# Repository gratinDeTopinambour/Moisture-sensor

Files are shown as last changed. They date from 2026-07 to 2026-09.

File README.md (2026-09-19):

# 🌿 Capacitive Soil Moisture Sensor

A complete **open-source capacitive soil moisture sensor project** based on the **STM32U073CB** microcontroller.

This repository contains all resources for the project:
* 📐 **3D Design**: Modular enclosure for 3D printing.
* 🔌 **Electronics (V1 & V2)**: KiCad files, Gerbers, BOM, PDF schematics, and 3D models.
* 💻 **Firmware**: C/C++ source code optimized for STM32 (STM32CubeIDE / STM32CubeMX project).
* 📖 **Documentation**: User manual and component datasheets.

---

## 🖼️ Project Overview

| Complete Enclosure | Assembled PCB |
| :---: | :---: |
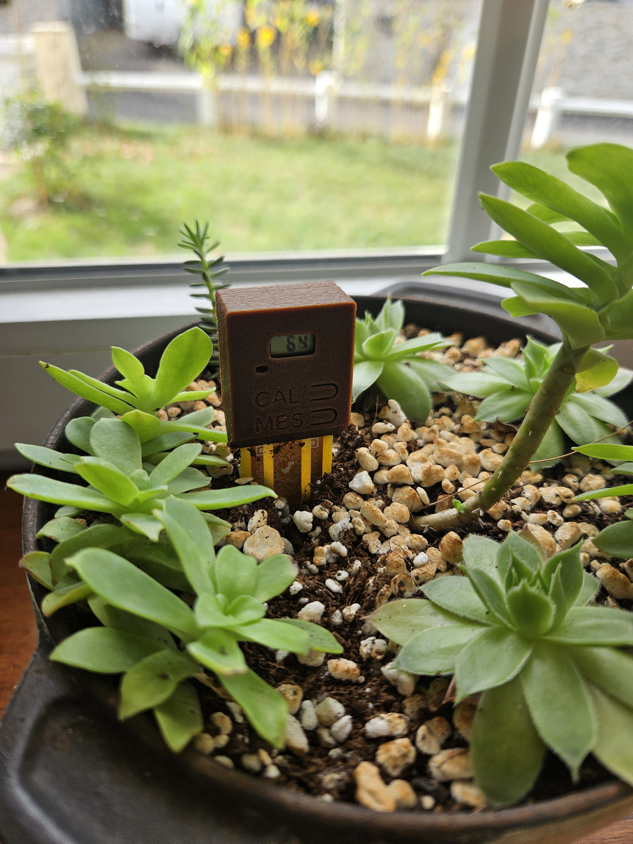
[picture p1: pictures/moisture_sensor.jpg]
Moisture Sensor
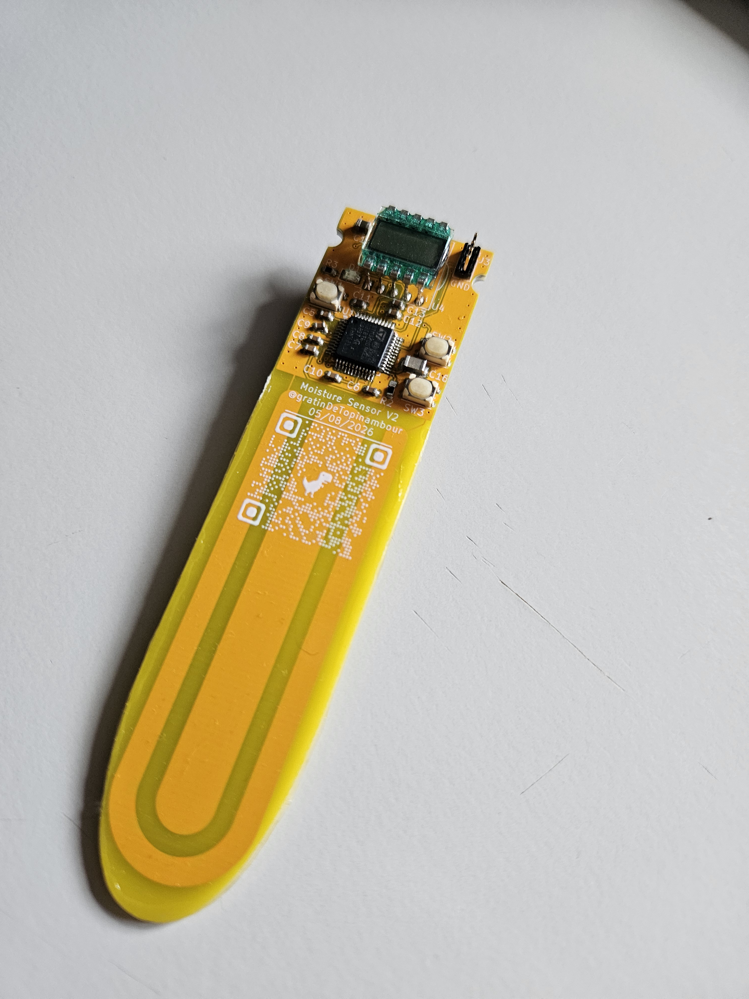
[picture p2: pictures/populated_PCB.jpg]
Assembled PCB
|  |  |

---

## 📂 Project Structure

```text
Moisture-sensor/
├── 3D_design/                             # CAD files for 3D printing
│   ├── moisture_sensor_capot.3mf         # Main top cover (3MF)
│   ├── moisture_sensor_capot_ecran.stl   # Top cover with display cutout (STL)
│   └── moisture_sensor_capot_pile.stl    # Battery hatch / compartment (STL)
│
├── Electronics/                           # Electronics design files
│   ├── datasheet/                         # Component datasheets
│   ├── Moisture_sensorV1/                 # First revision
│   └── Moisture_sensorV2/                 # Revision V2 (Main)
│       ├── 3D_model/                      # Complete PCB 3D STEP model
│       ├── BOM/                           # Bill of Materials (BOM)
│       ├── gerber_file/                   # Gerber files for PCB manufacturing
│       ├── KICAD/                         # KiCad CAD project (Schematics + PCB)
│       └── pdf_version/                   # Schematics in PDF format
│
├── Program/                               # Firmware & Source code
│   └── STM32U073CB/                       # STM32CubeIDE / CubeMX project
│       ├── Core/                          # Application source code (Inc, Src, Main)
│       ├── Drivers/                       # STM32 HAL and CMSIS drivers
│       ├── Capacitive_Moisture_sensor.ioc # STM32CubeMX configuration
│       ├── Capacitive_Moisture_sensor Debug.launch # Debug launch configuration
│       └── STM32U073CBTX_FLASH.ld         # Flash linker script
│
├── pictures/                              # Project pictures
│   ├── moisture_sensor.jpg
│   └── populated_PCB.jpg
│
├── Moisture_sensor_User_Manual.pdf        # Complete user manual (PDF)
├── Moisture_sensor_User_Manual.odt        # Editable user manual (ODT)
└── README.md                              # Main repository documentation

---

## ⚡ Technical Specifications

* **Microcontroller**: STM32U073CB (Ultra-low-power ARM Cortex-M0+).
* **Measurement Technology**: Capacitive (corrosion-resistant compared to resistive sensors).
* **PCB Design**: Designed with **KiCad** (V2 revision available with production-ready Gerber files).
* **Power Supply**: Designed for battery operation with a quick-access hatch.
* **Display (Optional)**: Screen support using the custom top cover.

---

## 🖨️ 3D Printed Enclosure

Parts are located in the `3D_design/` directory.

| Part | Format | Description |
| :--- | :--- | :--- |
| `moisture_sensor_capot.3mf` | `.3mf` | Standard solid top cover |
| `moisture_sensor_capot_ecran.stl` | `.stl` | Top cover with cutout for display integration |
| `moisture_sensor_capot_pile.stl` | `.stl` | Battery compartment housing / cover |

---

## 💻 Firmware & Development

Source code is located in `Program/STM32U073CB/`.

### Prerequisites
* [STM32CubeIDE](https://www.st.com/en/development-tools/stm32cubeide.html) (recent version)
* Programmer / Debugger (ST-Link V2 / V3)

### Building and Flashing
1. Open **STM32CubeIDE**.
2. Import the project from `Program/STM32U073CB`.
3. If you wish to modify pinout or peripheral configurations, open `Capacitive_Moisture_sensor.ioc` with STM32CubeMX.
4. Build (`Build Project`) then flash the microcontroller using the included debug configuration (`Capacitive_Moisture_sensor Debug.launch`).

---

## 🏭 PCB Manufacturing (Hardware V2)

To manufacture the V2 PCB:
1. Production-ready manufacturing files (JLCPCB, PCBWay, etc.) are located in `Electronics/Moisture_sensorV2/gerber_file/`.
2. The Bill of Materials (BOM) for soldering is available in `Electronics/Moisture_sensorV2/BOM/`.
3. Schematics can be viewed in KiCad or directly in `Electronics/Moisture_sensorV2/pdf_version/`.

---

## 📖 User Manual

To learn more about calibration, installation, and daily usage of the sensor, refer to:
📄 [Moisture_sensor_User_Manual.pdf](Moisture_sensor_User_Manual.pdf)

---

## 📜 License

This project is released under an open-source license. You are free to use, modify, and distribute it.

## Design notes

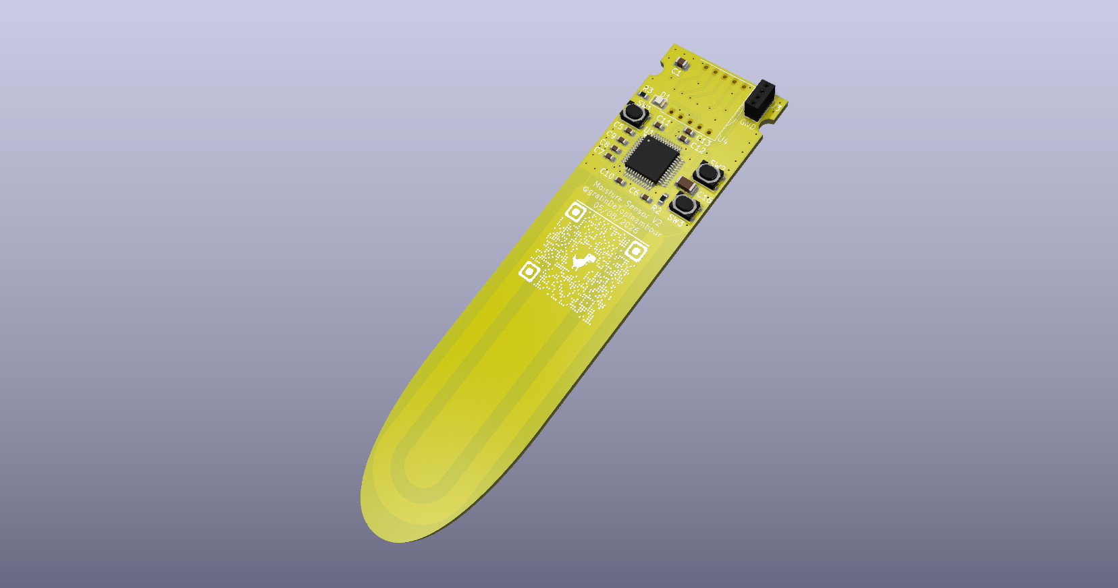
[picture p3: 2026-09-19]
Electronics/Moisture_sensorV2/pdf_version/moisture_sensor_V2.png

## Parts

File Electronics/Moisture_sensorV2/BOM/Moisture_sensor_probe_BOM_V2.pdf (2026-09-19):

Feuille1

# Reference Value Footprint

C1 | 10uF | 0805_2012Metric
C5 | 100nF | 0603_1608Metric
C6 | 100nF | 0603_1608Metric
C7 | 1uF | 0603_1608Metric
C8 | 100nF | 0603_1608Metric
C9 | 100nF | 0603_1608Metric
C10 | 1uF | 0603_1608Metric
C11 | 100nF | 0603_1608Metric
C12 | 100nF | 0603_1608Metric
C13 | 100nF | 0603_1608Metric
C15 | Cprobe
C16 | 47nF | 1206_3216Metric
D1 | RED_LED | 0805_2012Metric
J1 | | CR2032_holder_smd
J3 | ST-link | PinHeader_1x04_P1,26mm_Vertical
R2 | 1k | 0603_1608Metric
R3 | 200 | 0603_1608Metric
SW1 | NRST | SW_Push_1P1T_NO_Vertical_Wuerth_434133025816
SW2 | SwA | SW_Push_1P1T_NO_Vertical_Wuerth_434133025816
SW3 | SwB | SW_Push_1P1T_NO_Vertical_Wuerth_434133025816
U1 | | LQFP-48_7x7mm_P0.5mm
U4 | LCD_3_DIGIT LCD_DISPLAY_THT_10PIN

CR2032_holde
r_smd

STM32U073C8
Tx

part | datasheet
C0805C106K3PACTU | KEM_C1006_X5R_SMD
C0603C104K5RACTU | KEM_C1002_X7R_SMD
C0603C104K5RACTU | KEM_C1002_X7R_SMD
C0603C105K4RACTU | KEM_C1002_X7R_SMD
C0603C104K5RACTU | KEM_C1002_X7R_SMD
C0603C104K5RACTU | KEM_C1002_X7R_SMD
C0603C105K4RACTU | KEM_C1002_X7R_SMD
C0603C104K5RACTU | KEM_C1002_X7R_SMD
C0603C104K5RACTU | KEM_C1002_X7R_SMD
C0603C104K5RACTU | KEM_C1002_X7R_SMD
NA
ECH-U1C473GX5 | ECH-U1C473GX5
150080RS75000 | 150080RS75000
S8421-45R | ePH
CRCW06031K00FKEA | dcrcwe3
CRCW0603200RFKEA | dcrcwe3
SKRPABE010 | product_spec_skrpabe010_en_c1c577738a
SKRPABE010 | product_spec_skrpabe010_en_c1c577738a
SKRPABE010 | product_spec_skrpabe010_en_c1c577738a
STM32U073C8T6 | stm32u073c8
NA

# digikey ref

399-11939
399-C0603C104K5RACTUCT-ND
399-C0603C104K5RACTUCT-ND
399-C0603C105K4RACTUCT-ND
399-C0603C104K5RACTUCT-ND
399-C0603C104K5RACTUCT-ND
399-C0603C105K4RACTUCT-ND
399-C0603C104K5RACTUCT-ND
399-C0603C104K5RACTUCT-ND
399-C0603C104K5RACTUCT-ND

PCF1185CT-ND
732-4984-1-ND

455-1719-ND

541-1.00KHCT-ND
541-200HCT-ND

4809-SKRPABE010CT-ND

4809-SKRPABE010CT-ND

4809-SKRPABE010CT-ND

497-STM32U073C8T6-ND

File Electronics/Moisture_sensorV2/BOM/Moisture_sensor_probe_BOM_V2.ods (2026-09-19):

Reference | Value | Footprint | part | datasheet | digikey ref
C1 | 10uF | 0805_2012Metric | C0805C106K3PACTU | KEM_C1006_X5R_SMD | 399-11939
C5 | 100nF | 0603_1608Metric | C0603C104K5RACTU | KEM_C1002_X7R_SMD | 399-C0603C104K5RACTUCT-ND
C6 | 100nF | 0603_1608Metric | C0603C104K5RACTU | KEM_C1002_X7R_SMD | 399-C0603C104K5RACTUCT-ND
C7 | 1uF | 0603_1608Metric | C0603C105K4RACTU | KEM_C1002_X7R_SMD | 399-C0603C105K4RACTUCT-ND
C8 | 100nF | 0603_1608Metric | C0603C104K5RACTU | KEM_C1002_X7R_SMD | 399-C0603C104K5RACTUCT-ND
C9 | 100nF | 0603_1608Metric | C0603C104K5RACTU | KEM_C1002_X7R_SMD | 399-C0603C104K5RACTUCT-ND
C10 | 1uF | 0603_1608Metric | C0603C105K4RACTU | KEM_C1002_X7R_SMD | 399-C0603C105K4RACTUCT-ND
C11 | 100nF | 0603_1608Metric | C0603C104K5RACTU | KEM_C1002_X7R_SMD | 399-C0603C104K5RACTUCT-ND
C12 | 100nF | 0603_1608Metric | C0603C104K5RACTU | KEM_C1002_X7R_SMD | 399-C0603C104K5RACTUCT-ND
C13 | 100nF | 0603_1608Metric | C0603C104K5RACTU | KEM_C1002_X7R_SMD | 399-C0603C104K5RACTUCT-ND
C15 | Cprobe |  | NA
C16 | 47nF | 1206_3216Metric | ECH-U1C473GX5 | ECH-U1C473GX5 | PCF1185CT-ND
D1 | RED_LED | 0805_2012Metric | 150080RS75000 | 150080RS75000 | 732-4984-1-ND
J1 | CR2032_holder_smd | CR2032_holder_smd | S8421-45R | ePH | 455-1719-ND
J3 | ST-link | PinHeader_1x04_P1,26mm_Vertical
R2 | 1k | 0603_1608Metric | CRCW06031K00FKEA | dcrcwe3 | 541-1.00KHCT-ND
R3 | 200 | 0603_1608Metric | CRCW0603200RFKEA | dcrcwe3 | 541-200HCT-ND
SW1 | NRST | SW_Push_1P1T_NO_Vertical_Wuerth_434133025816 | SKRPABE010 | product_spec_skrpabe010_en_c1c577738a | 4809-SKRPABE010CT-ND
SW2 | SwA | SW_Push_1P1T_NO_Vertical_Wuerth_434133025816 | SKRPABE010 | product_spec_skrpabe010_en_c1c577738a | 4809-SKRPABE010CT-ND
SW3 | SwB | SW_Push_1P1T_NO_Vertical_Wuerth_434133025816 | SKRPABE010 | product_spec_skrpabe010_en_c1c577738a | 4809-SKRPABE010CT-ND
U1 | STM32U073C8Tx | LQFP-48_7x7mm_P0.5mm | STM32U073C8T6 | stm32u073c8 | 497-STM32U073C8T6-ND
U4 | LCD_3_DIGIT | LCD_DISPLAY_THT_10PIN | NA

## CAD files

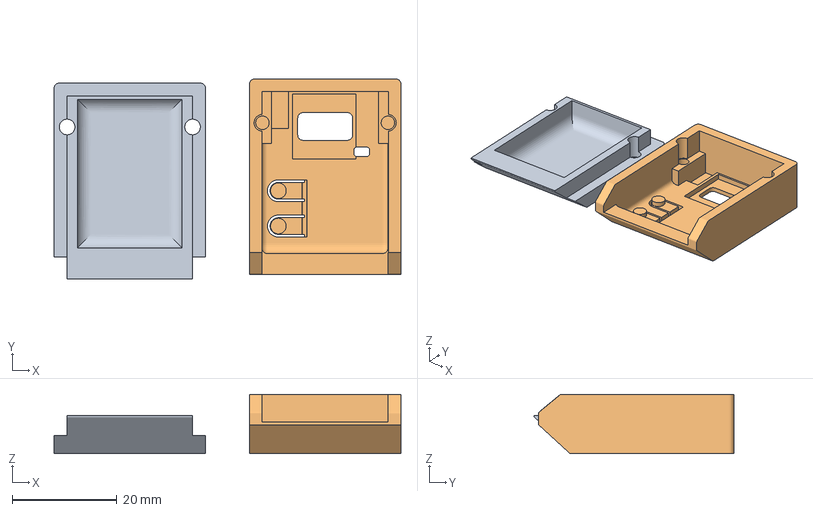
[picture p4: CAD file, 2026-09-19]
3D_design/moisture_sensor_capot.3mf
66.4 x 38.3 x 11.3 mm
moisture_sensor_capot_pile.stl
moisture_sensor_capot_ecran.stl

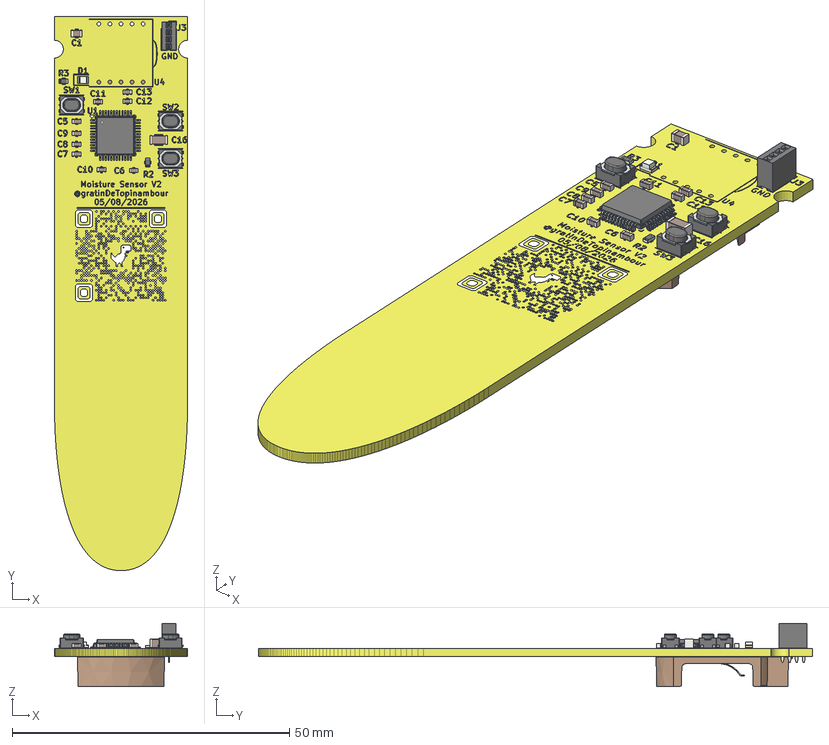
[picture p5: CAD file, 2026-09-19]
Electronics/Moisture_sensorV2/3D_model/moisture_sensor_3D.step
24.0 x 100.0 x 11.4 mm
Frame x 3
Cover x 3
Stem x 3
Terminal x 12
C_0603_1608Metric x 9
LED_0805_2012Metric
R_0603_1608Metric x 2
LQFP-48_7x7mm_P0.5mm
PinSocket_1x04_P1.27mm_Vertical
C_1206_3216Metric
C_0805_2012Metric
S842_HOLDER
S842-REAR-CONTACT
HDS842-CONTACT
moisture_sensor_silkscreen x 2
moisture_sensor_PCB

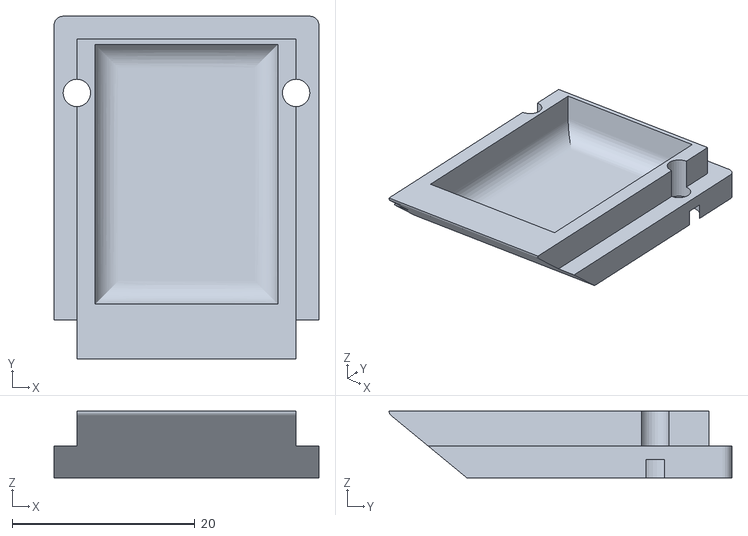
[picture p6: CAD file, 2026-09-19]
3D_design/moisture_sensor_capot_pile.stl
29.0 x 37.5 x 7.30

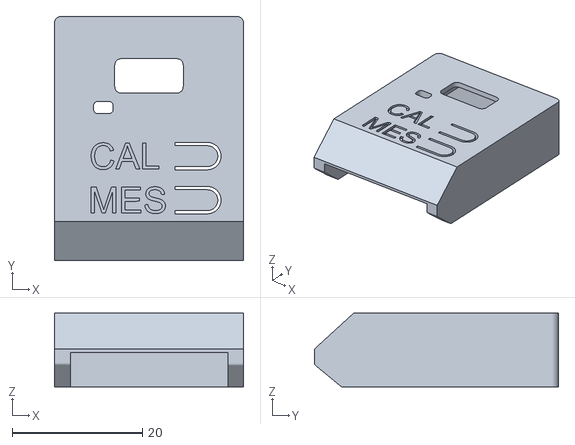
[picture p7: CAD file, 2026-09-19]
3D_design/moisture_sensor_capot_ecran.stl
29.0 x 37.4 x 11.3

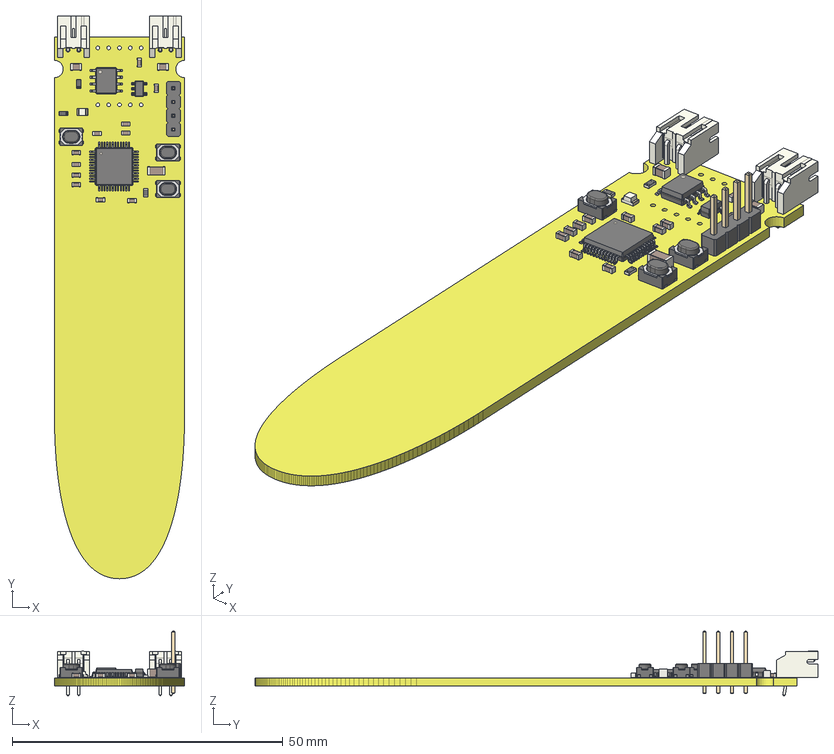
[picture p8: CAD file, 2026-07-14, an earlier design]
Electronics/Moisture_sensorV1/3D_model/moisture_sensor_3D.step
24.0 x 103.8 x 11.9 mm
Frame x 3
Cover x 3
Stem x 3
Terminal x 12
C_0603_1608Metric x 11
LED_0805_2012Metric
SOT-23-5
R_0603_1608Metric x 3
JST_S2B_PH_K x 2
LQFP-48_7x7mm_P0.5mm
PinHeader_1x04_P254mm_Vertical
C_0805_2012Metric x 2
C_1206_3216Metric
SOIC-8_3.9x4.9mm_P1.27mm
moisture_sensor_PCB

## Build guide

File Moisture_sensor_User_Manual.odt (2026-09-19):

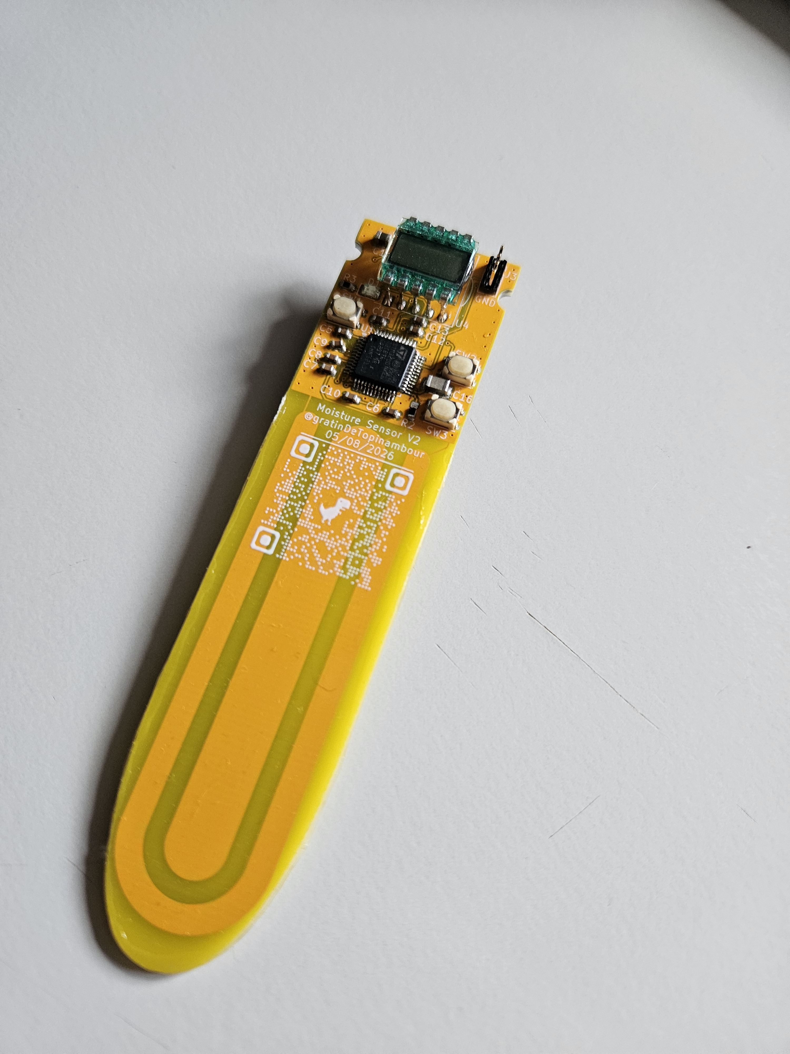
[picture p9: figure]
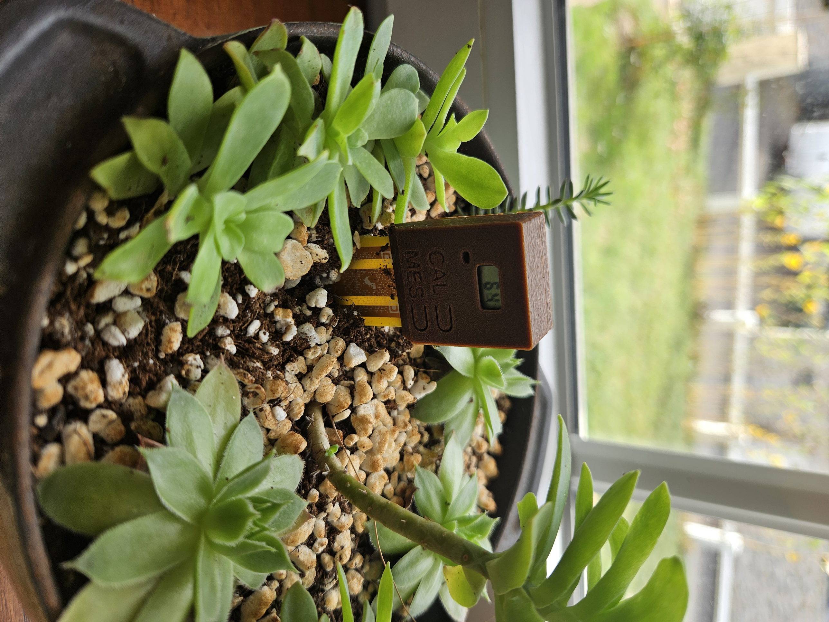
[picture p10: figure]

Moisture sensor

User Manual

# Introduction

The purpose of this document is to explain how to use the moisture sensor.

This device is designed to show the humidity level of a flower pot. After user calibration the moisture-sensor will show the humidity level of a flower pot and if the level is under 20% a red led will blink to indicate low humidity level.

# System Overview

## Functional Description

The moisture sensor operates with 3 push button and one LCD screen

LCD screen: show the humidity level in %

LCD screen

ST-LINK

Reset

Calibration

Measure

Capacitive probe

ST-LINK: port used for communication, mainly use for debug and programming

Reset: Button used to reset the board, mainly use for debug and programming

Calibration: Button used for calibration

Measure: Button used for measuring humidity level

Capacitive probe: need to be in the dirt

## Initialisation:

Place any CR2032 battery cell in the back slot then press the reset button.

Program the board with an st-link and the program available on Git-Hub

Put the 3D print cover available on Git-Hub

The moisture probe is now fully fonctionnal

# How to use

## Calibration

Prepare two pot. One with dry soil and the other with wet soil.

Place the probe inside the dry soil and press the calibration button.

Once you see the « SEC » message on the screen press the calibration button a second time.

The probe will calibrate in a few seconde

Once you see the « EAU » message on the screen place the probe in the wet soil and press calibration button

The probe will calibrate in a few seconde

once everything is done press the measure button to check if the humidity level is OK

## Usage

Once the calibration is done.

Place the probe in the flower pot.

Press Measure button to update the humidity level.

The humidity level will update every 30min or when you press the MES button

If the humidity level goes under 20% the probe will blink

Moisture-sensor, User manual

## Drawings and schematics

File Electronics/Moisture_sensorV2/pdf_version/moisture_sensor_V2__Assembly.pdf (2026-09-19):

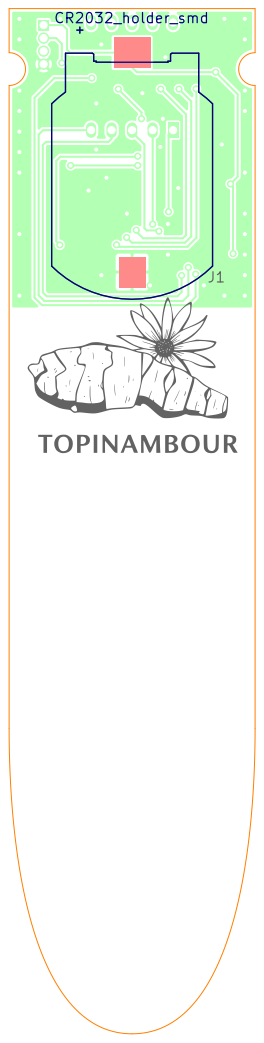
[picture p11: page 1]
D Date:; Size: A4; Rev:; CR2032_holder_smd

Board2Pdf: Colored BOT - Page 1/2

Sheet: Colored BOT
File: moisture_sensor.kicad_pcb
Title:
KiCad E.D.A. 10.0.3

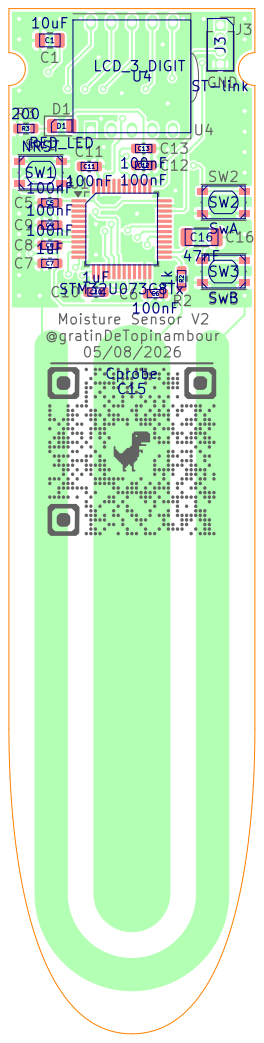
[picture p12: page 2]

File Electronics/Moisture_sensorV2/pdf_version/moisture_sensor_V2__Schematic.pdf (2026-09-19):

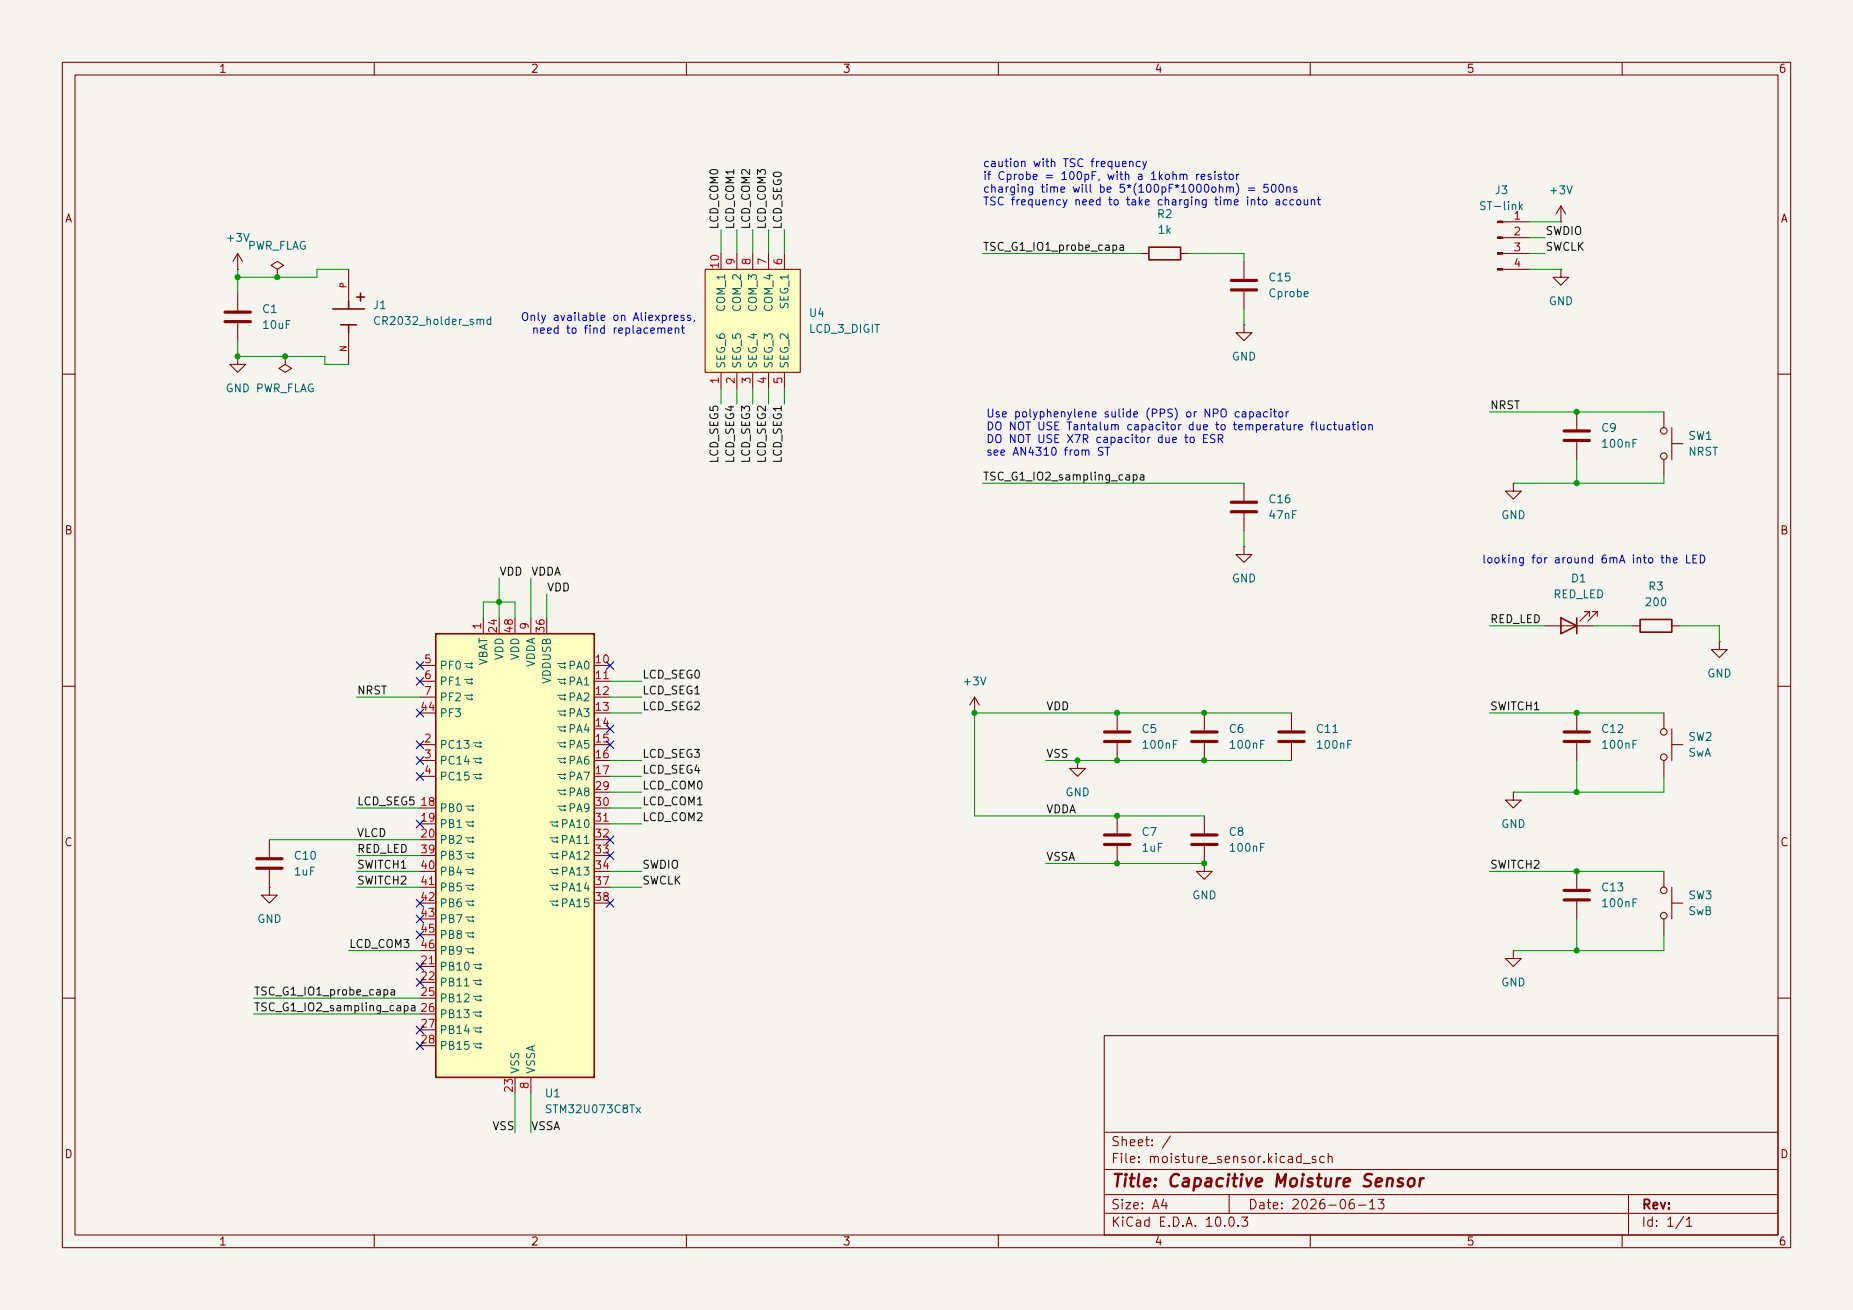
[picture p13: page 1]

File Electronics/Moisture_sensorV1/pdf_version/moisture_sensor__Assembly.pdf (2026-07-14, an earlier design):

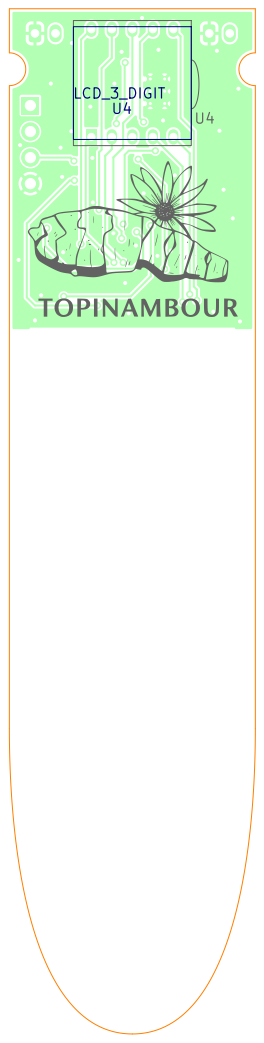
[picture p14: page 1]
D Date:; Size: A4; Rev:; LCD_3_DIGIT U4

Board2Pdf: Colored BOT - Page 1/2

Sheet: Colored BOT
File: moisture_sensor.kicad_pcb
Title:
KiCad E.D.A. 10.0.3

J1 U1

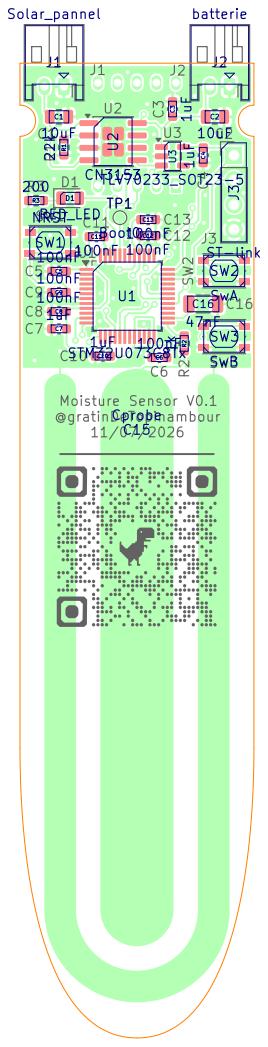
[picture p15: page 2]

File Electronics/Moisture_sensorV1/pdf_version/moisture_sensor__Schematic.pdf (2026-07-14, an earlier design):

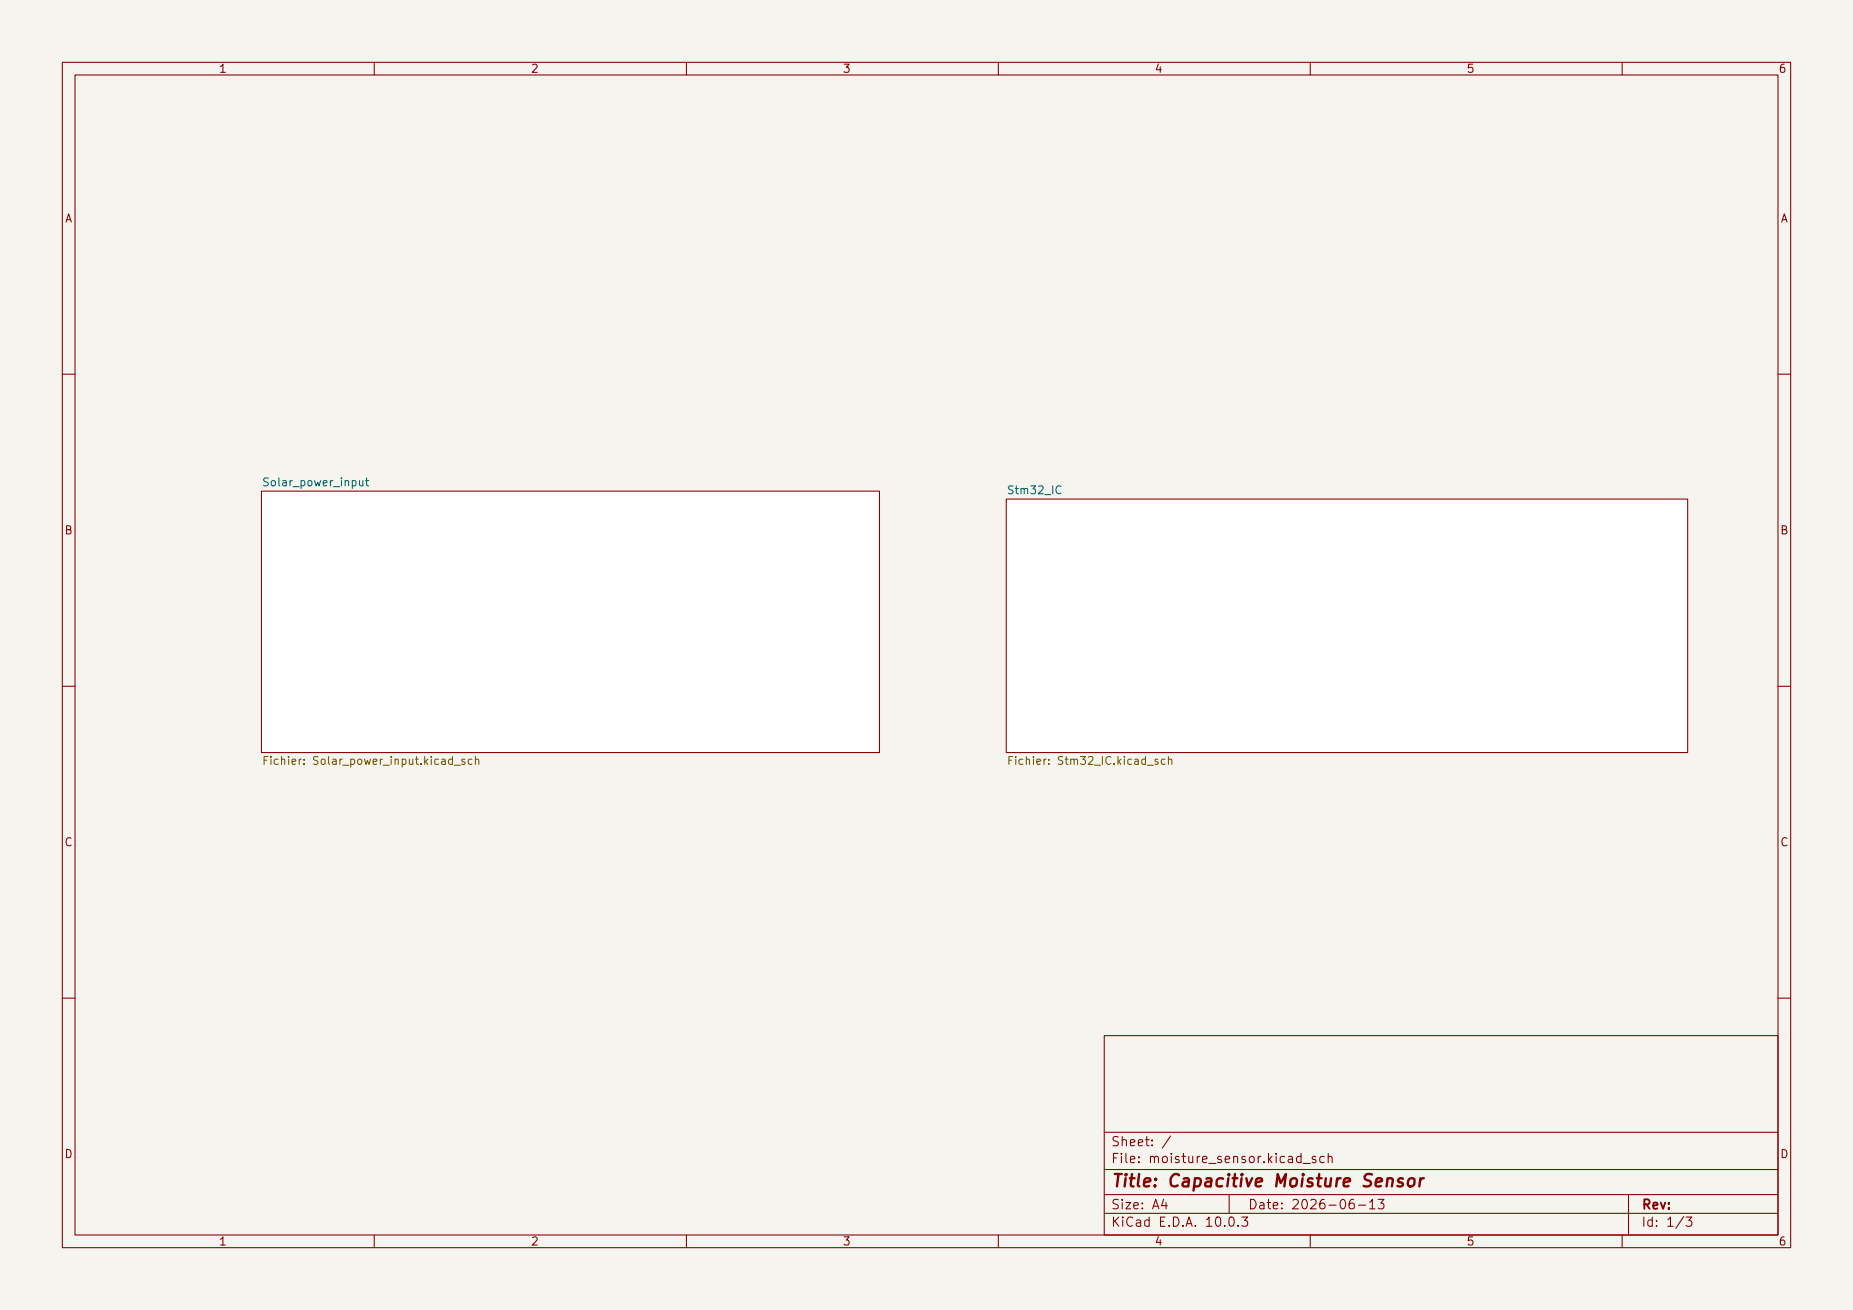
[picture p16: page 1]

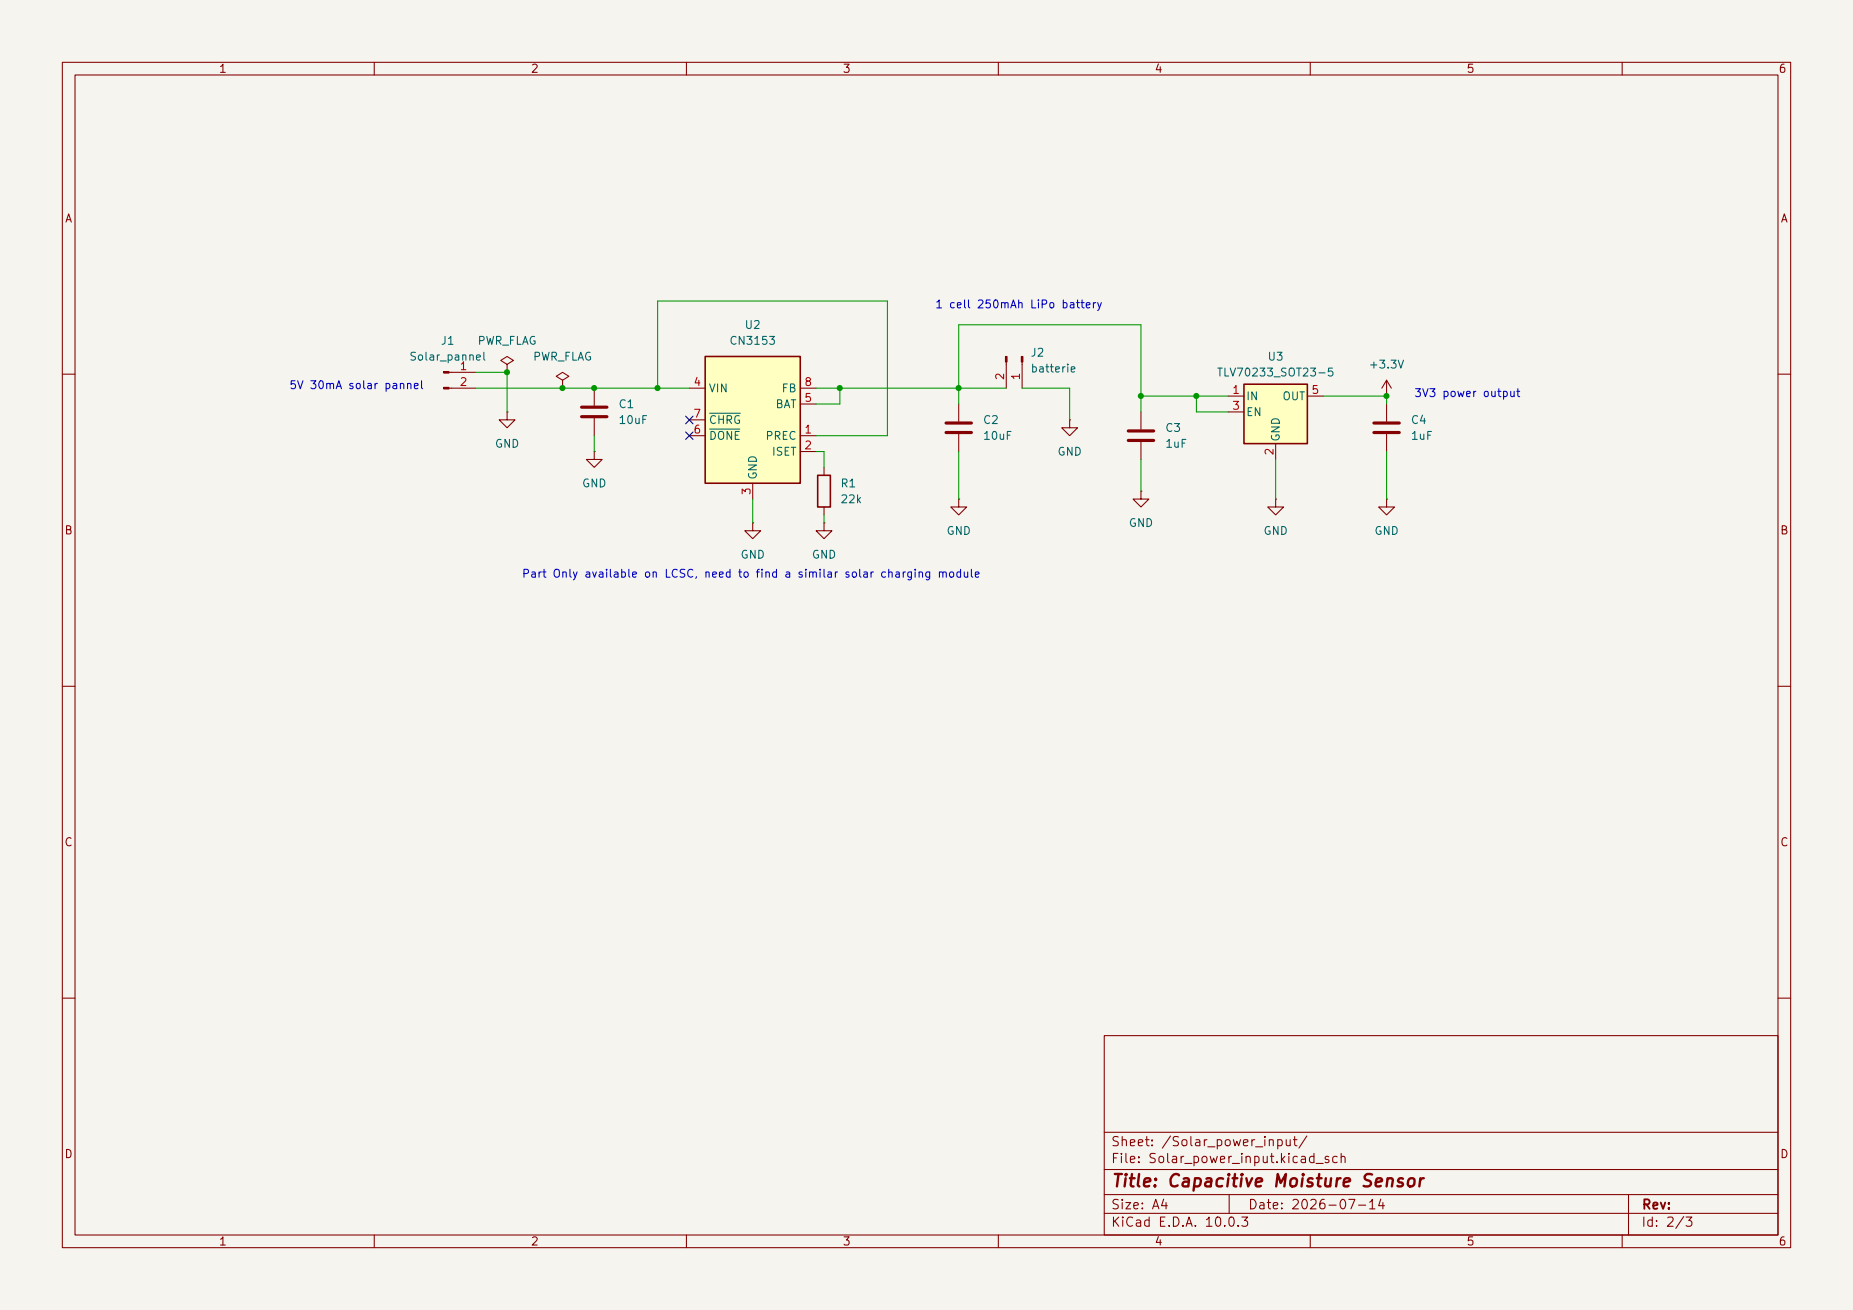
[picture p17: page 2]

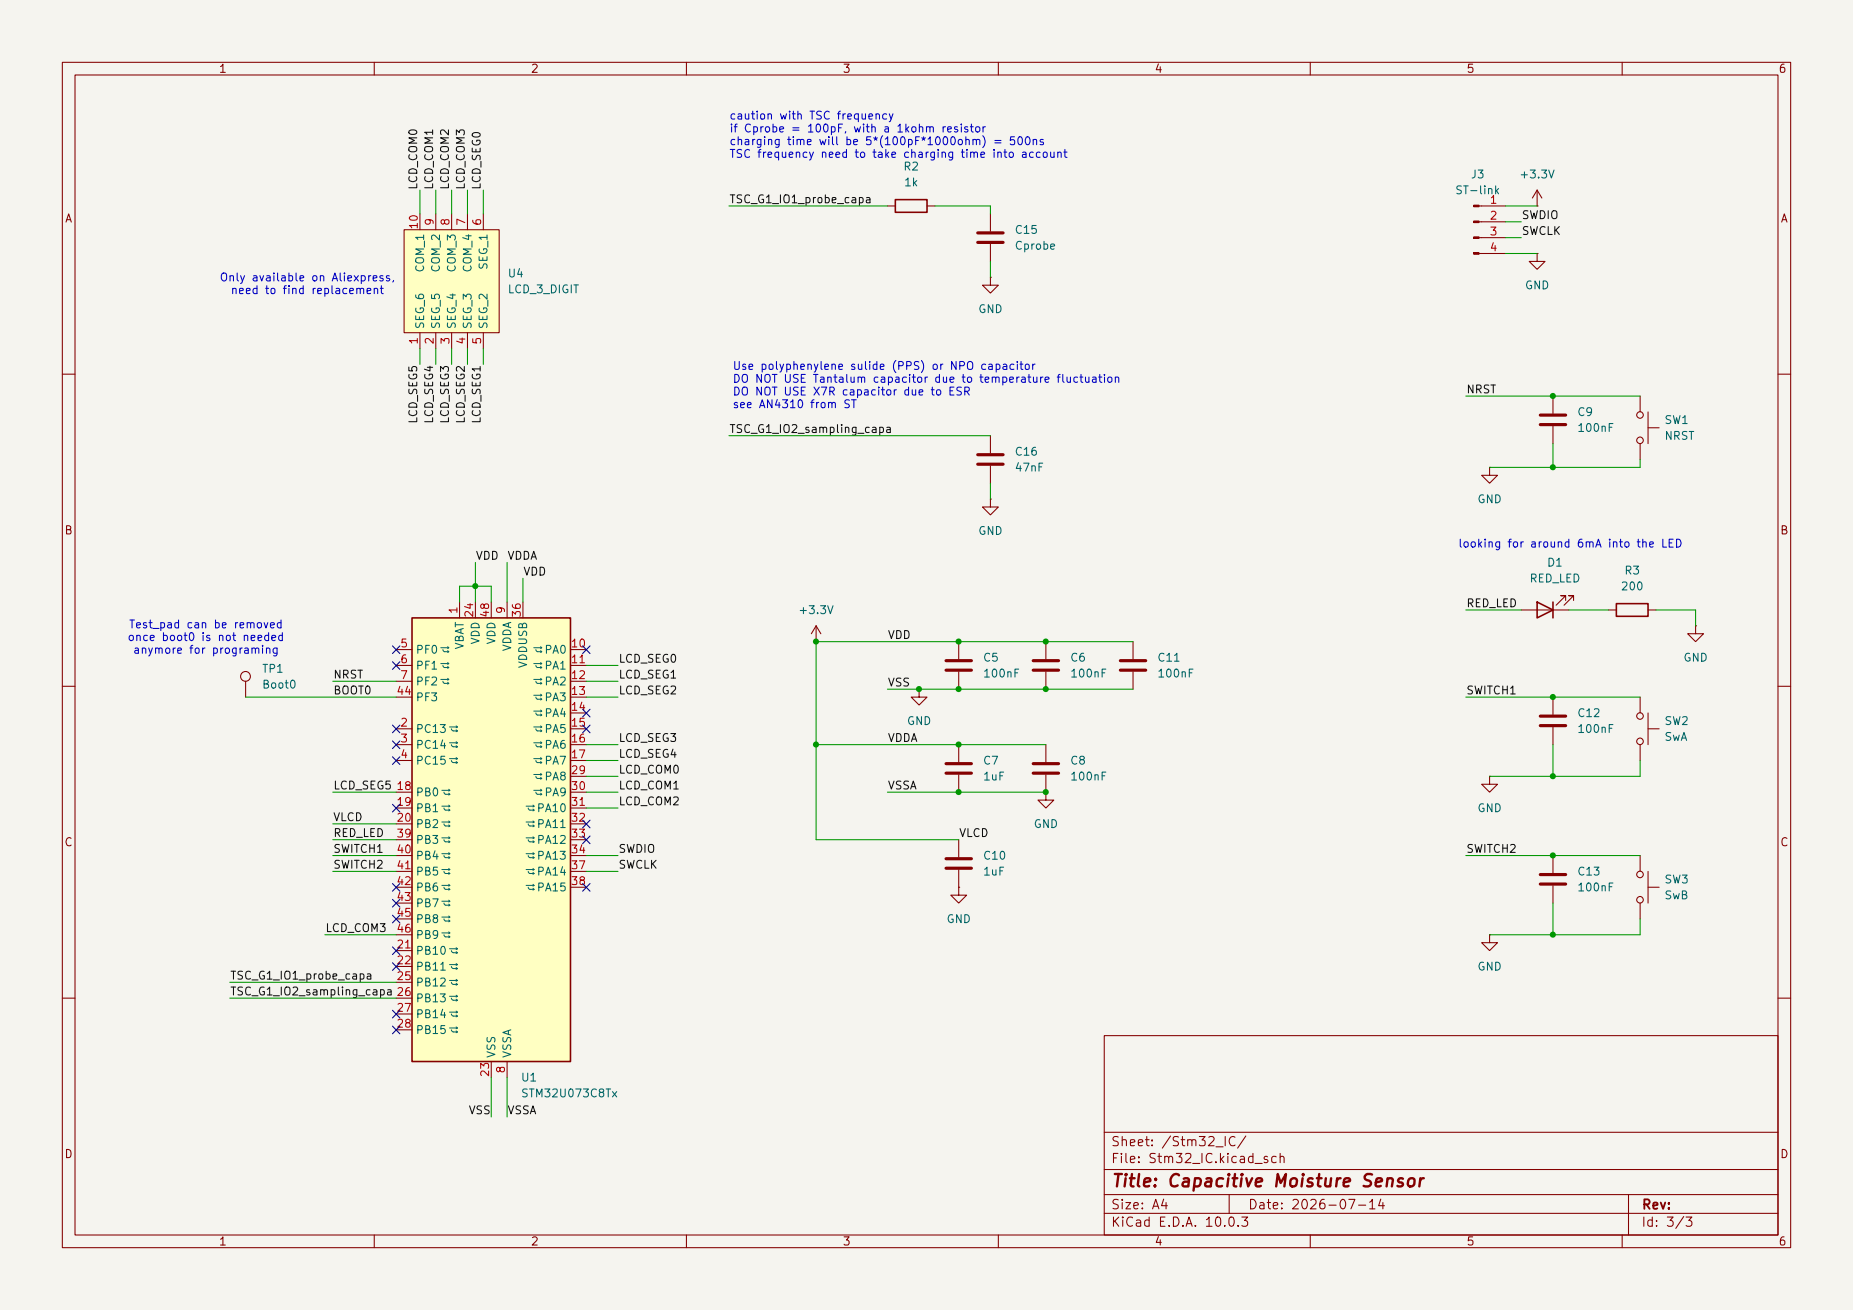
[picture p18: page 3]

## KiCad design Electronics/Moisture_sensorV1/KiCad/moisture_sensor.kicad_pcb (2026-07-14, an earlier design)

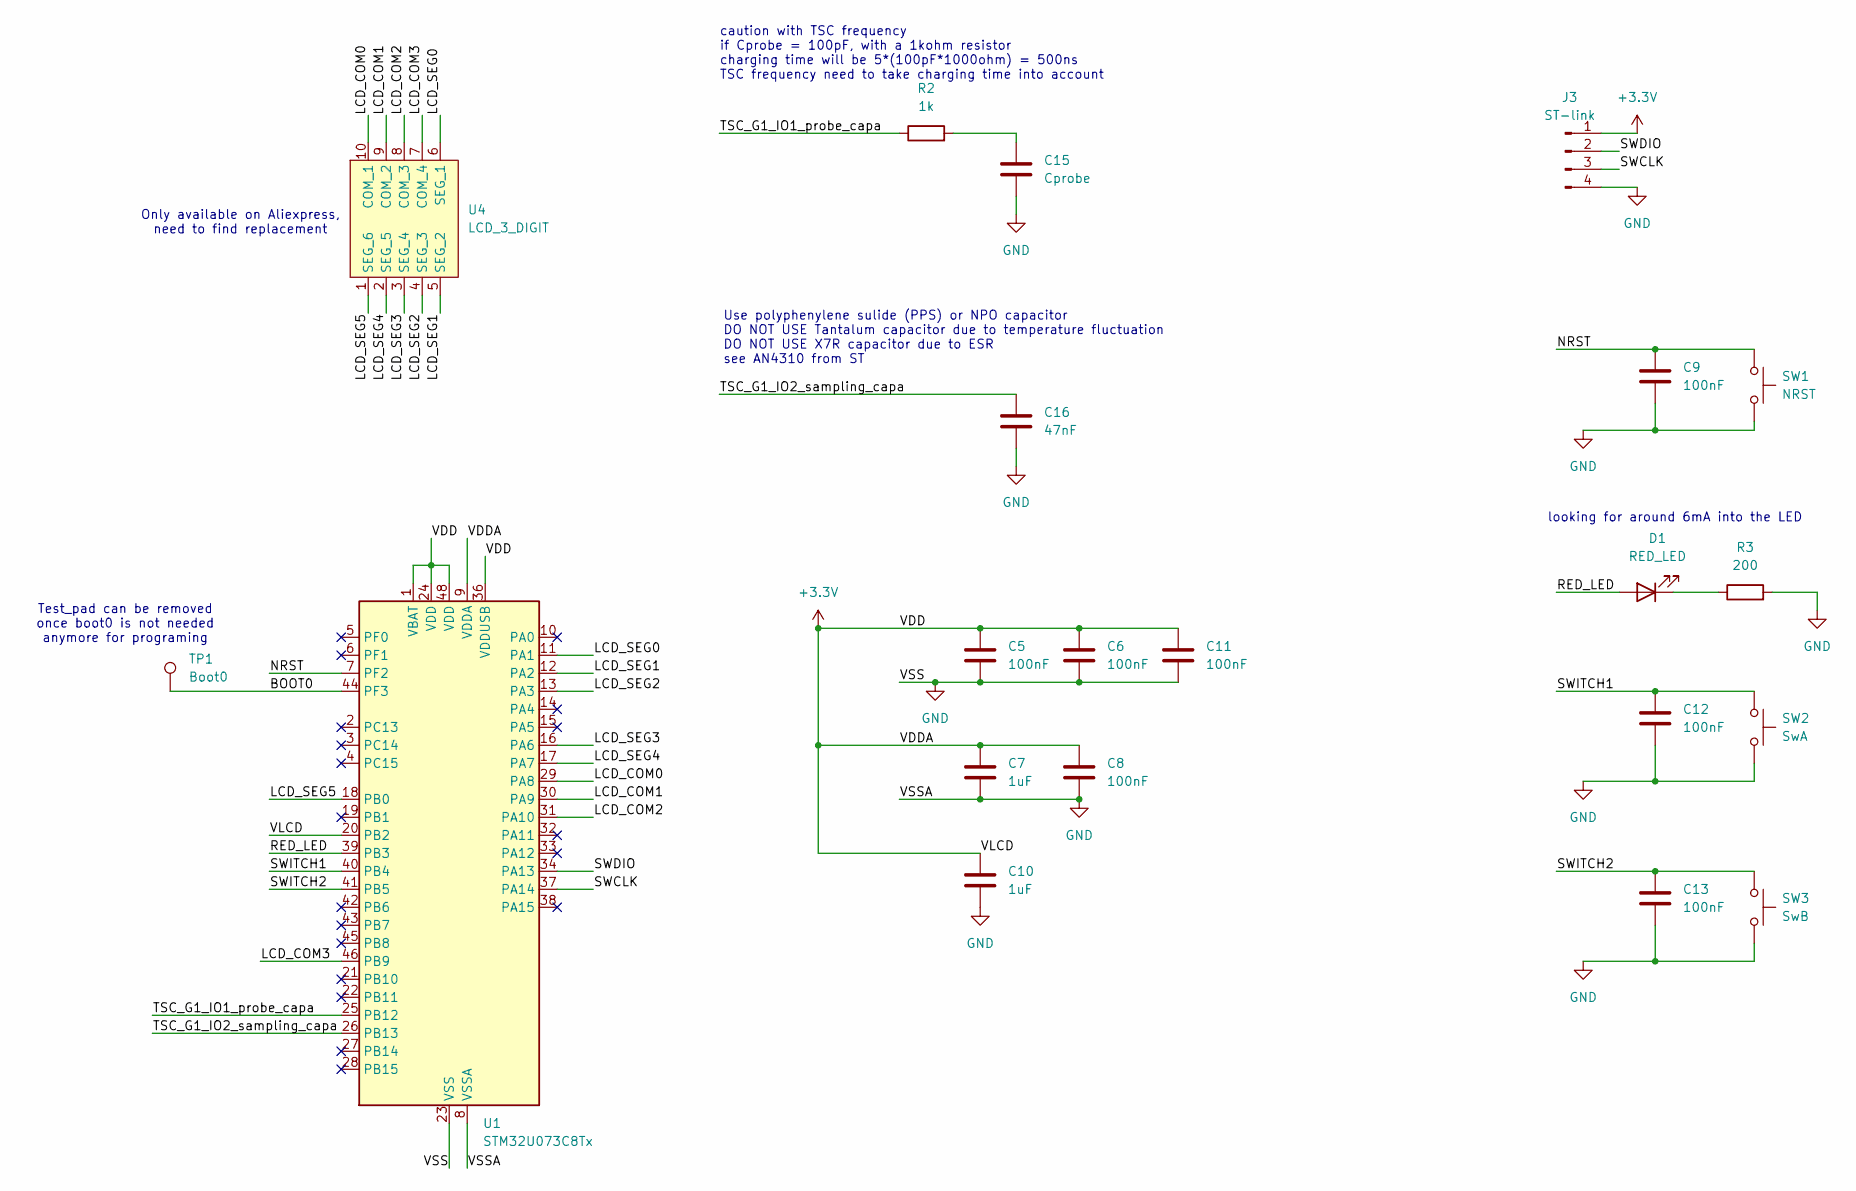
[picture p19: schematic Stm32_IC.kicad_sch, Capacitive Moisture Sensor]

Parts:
C5, C6, C8, C9, C11, C12, C13: 100nF; C_0603_1608Metric
C7, C10: 1uF; C_0603_1608Metric
C15: Cprobe; C_Soil_Moisture_Probe
C16: 47nF; C_1206_3216Metric
D1: RED_LED; LED_0805_2012Metric
J3: ST-link; PinHeader_1x04_P2.54mm_Vertical
R2: 1k; R_0603_1608Metric
R3: 200; R_0603_1608Metric
SW1: NRST; SW_Push_1P1T_NO_Vertical_Wuerth_434133025816
SW2: SwA; SW_Push_1P1T_NO_Vertical_Wuerth_434133025816
SW3: SwB; SW_Push_1P1T_NO_Vertical_Wuerth_434133025816
TP1: Boot0; TestPoint_Pad_D1.0mm
U1: STM32U073C8Tx; LQFP-48_7x7mm_P0.5mm
U4: LCD_3_DIGIT; LCD_DISPLAY_THT_10PIN

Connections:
+3.3V: C5.1, C6.1, C7.1, C8.1, C10.1, C11.1, J3.1, U1.1 (VBAT), U1.9 (VDDA), U1.20 (PB2), U1.24 (VDD), U1.36 (VDDUSB), U1.48 (VDD); also elsewhere on the board
/Stm32_IC/BOOT0: TP1.1 (1_1), U1.44 (PF3)
/Stm32_IC/LCD_COM0: U1.29 (PA8), U4.10 (COM_1)
/Stm32_IC/LCD_COM1: U1.30 (PA9), U4.9 (COM_2)
/Stm32_IC/LCD_COM2: U1.31 (PA10), U4.8 (COM_3)
/Stm32_IC/LCD_COM3: U1.46 (PB9), U4.7 (COM_4)
/Stm32_IC/LCD_SEG0: U1.11 (PA1), U4.6 (SEG_1)
/Stm32_IC/LCD_SEG1: U1.12 (PA2), U4.5 (SEG_2)
/Stm32_IC/LCD_SEG2: U1.13 (PA3), U4.4 (SEG_3)
/Stm32_IC/LCD_SEG3: U1.16 (PA6), U4.3 (SEG_4)
/Stm32_IC/LCD_SEG4: U1.17 (PA7), U4.2 (SEG_5)
/Stm32_IC/LCD_SEG5: U1.18 (PB0), U4.1 (SEG_6)
/Stm32_IC/NRST: C9.1, SW1.1, U1.7 (PF2)
/Stm32_IC/RED_LED: D1.2 (A), U1.39 (PB3)
/Stm32_IC/SWCLK: J3.3, U1.37 (PA14)
/Stm32_IC/SWDIO: J3.2, U1.34 (PA13)
/Stm32_IC/SWITCH1: C12.1, SW2.1, U1.40 (PB4)
/Stm32_IC/SWITCH2: C13.1, SW3.1, U1.41 (PB5)
/Stm32_IC/TSC_G1_IO1_probe_capa: R2.1, U1.25 (PB12)
/Stm32_IC/TSC_G1_IO2_sampling_capa: C16.1, U1.26 (PB13)
GND: C5.2, C6.2, C7.2, C8.2, C9.2, C10.2, C11.2, C12.2, C13.2, C15.2, C16.2, J3.4, R3.2, SW1.2, SW2.2, SW3.2, U1.8 (VSSA), U1.23 (VSS), U1.35 (VSS), U1.47 (VSS); also elsewhere on the board
unnamed: C15.1, R2.2
unnamed: D1.1 (K), R3.1

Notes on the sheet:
Use polyphenylene sulide (PPS) or NPO capacitor DO NOT USE Tantalum capacitor due to temperature fluctuation DO NOT USE X7R capacitor due to ESR see AN4310 from ST
looking for around 6mA into the LED
Test_pad can be removed once boot0 is not needed anymore for programing
Only available on Aliexpress, need to find replacement
caution with TSC frequency if Cprobe = 100pF, with a 1kohm resistor charging time will be 5*(100pF*1000ohm) = 500ns TSC frequency need to take charging time into account

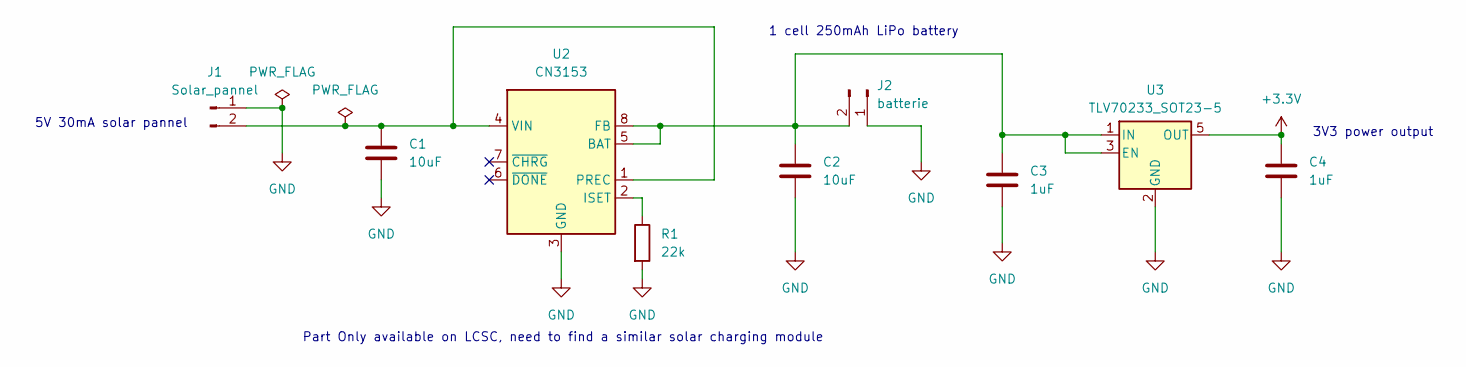
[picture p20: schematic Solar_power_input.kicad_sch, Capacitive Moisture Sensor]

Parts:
C1, C2: 10uF; C_0805_2012Metric
C3, C4: 1uF; C_0603_1608Metric
J1: Solar_pannel; JST_PH_S2B-PH-K_1x02_P2.00mm_Horizontal
J2: batterie; JST_PH_S2B-PH-K_1x02_P2.00mm_Horizontal
R1: 22k; R_0603_1608Metric
U2: CN3153; SOIC-8-1EP_3.9x4.9mm_P1.27mm_EP2.41x3.3mm_ThermalVias
U3: TLV70233_SOT23-5; SOT-23-5

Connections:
+3.3V: C4.1, U3.5 (OUT); also elsewhere on the board
GND: C1.2, C2.2, C3.2, C4.2, J1.1, J2.1, R1.2, U2.3 (GND), U2.9 (GND), U3.2 (GND); also elsewhere on the board
unnamed: C1.1, J1.2, U2.1 (PREC), U2.4 (VIN)
unnamed: C2.1, C3.1, J2.2, U2.5 (BAT), U2.8 (FB), U3.1 (IN), U3.3 (EN)
unnamed: R1.1, U2.2 (ISET)

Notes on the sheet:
Part Only available on LCSC, need to find a similar solar charging module
3V3 power output
1 cell 250mAh LiPo battery
5V 30mA solar pannel

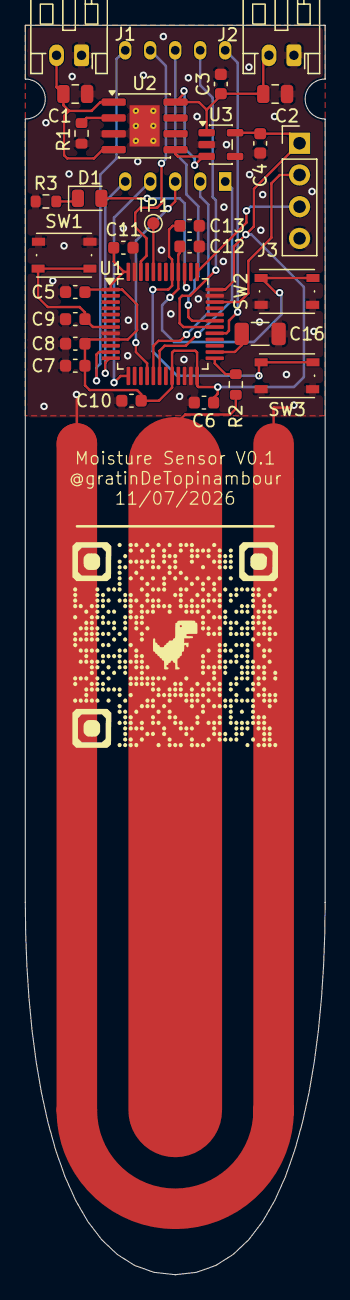
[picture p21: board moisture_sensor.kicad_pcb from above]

Board: 2 copper layers, 24.0 x 100.0 mm, 30 parts (1 on the bottom side), 26 nets.

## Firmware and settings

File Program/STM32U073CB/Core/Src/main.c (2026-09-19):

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
/* Includes ------------------------------------------------------------------*/
#include "main.h"

/* USER CODE BEGIN Includes */
#include "capacitive_sensor.h"
#include "LCD_3DIGIT.h"
#include <stdio.h>
/* USER CODE END Includes */


LCD_HandleTypeDef hlcd;

RTC_HandleTypeDef hrtc;

TSC_HandleTypeDef htsc;

/* USER CODE BEGIN PV */

uint32_t HTSC_value_min = 150;
uint32_t HTSC_value_max = 2600;
uint8_t humidity;
char lcd_txt[4] = "123";

Flag system_flag = {0};
State system_state = START;

uint32_t start_timer = 0;
uint32_t now_timer = 0;

volatile uint8_t StopMode_Activated = 0;

/* USER CODE END PV */

void SystemClock_Config(void);
static void MX_GPIO_Init(void);
static void MX_LCD_Init(void);
static void MX_TSC_Init(void);
static void MX_RTC_Init(void);
/* USER CODE BEGIN 0 */

// Optimized: Converts int to string without using the heavy sprintf library
void mini_sprintf(int n, char *s, uint8_t width, char pad)
{

	s[width-1] = '\0';
    // 1. Keep track of the sign and use the absolute value
    uint8_t is_negative = (n < 0);
    unsigned int num = is_negative ? -n : n;

    for (int8_t i = width - 2; i >= 0; i--) {
        // 2. Fill digits using the absolute value
        if (num > 0 || (i == width - 2 && num == 0)) {
            s[i] = (num % 10) + '0';
            num /= 10;
        }
        // 3. Place the negative sign once digits are done
        else if (is_negative) {
            s[i] = '-';
            is_negative = 0; // Sign is placed, don't place it again
        }
        // 4. Fill remaining space with padding
        else {
            s[i] = pad;
        }
    }
}

uint8_t update_capa_sensor(uint32_t max_val, uint32_t min_val, TSC_HandleTypeDef *htsc)
{
	uint32_t TSC_val1 = 0;
	uint32_t TSC_val2 = 0;
	int hum = 0;
	char hum_txt[4] = "000";

	TSC_val1 = read_capa_value(htsc);
	if (TSC_val1 == 0) return 200;

	TSC_val2 = read_capa_value(htsc);
	if (TSC_val2 == 0) return 200;

	if (TSC_val2 > TSC_val1 * 1.05 || TSC_val2 < TSC_val1 * 0.95) return 200;

	hum = ((TSC_val1 - min_val)*100)/(max_val - min_val);

	hum = 100 - hum;

	if(hum > 100) hum = 100;
	if(hum < 0) hum = 0;

	mini_sprintf(hum, hum_txt, sizeof(hum_txt), ' ');

	LCD_WriteDigit(hum_txt);

	return hum;
}

uint8_t cal_capa_sensor(uint32_t *max_val, uint32_t *min_val, TSC_HandleTypeDef *htsc)
{
	uint32_t TSC_val1 = 0;
	uint32_t TSC_val2 = 0;
	uint32_t start_time = HAL_GetTick();
	uint32_t now = HAL_GetTick();

	LCD_WriteDigit("cal");
	HAL_Delay(4000);

	LCD_WriteDigit("sec");
	start_time = HAL_GetTick();
	while(HAL_GPIO_ReadPin(CAL_SW_GPIO_Port, CAL_SW_Pin))
	{
		now = HAL_GetTick();
		if(now - start_time > 30000) return 0;
	}

	LCD_WriteDigit("*  ");
	HAL_Delay(1000);
	LCD_WriteDigit(" * ");
	HAL_Delay(1000);
	LCD_WriteDigit("  *");
	HAL_Delay(1000);
	LCD_WriteDigit("  o");
	HAL_Delay(1000);
	LCD_WriteDigit(" o ");
	HAL_Delay(1000);

	TSC_val1 = read_capa_value(htsc);
	if (TSC_val1 == 0) return 0;

	TSC_val2 = read_capa_value(htsc);
	if (TSC_val2 == 0) return 0;

	if (TSC_val2 > TSC_val1 * 1.05 || TSC_val2 < TSC_val1 * 0.95) return 0;

	*max_val = TSC_val1 * 1.05;

	LCD_WriteDigit("o  ");
	HAL_Delay(1000);

	LCD_WriteDigit("ok ");
	HAL_Delay(1000);


	LCD_WriteDigit("eau");
	start_time = HAL_GetTick();
	while(HAL_GPIO_ReadPin(CAL_SW_GPIO_Port, CAL_SW_Pin))
	{
		now = HAL_GetTick();
		if(now - start_time > 30000) return 0;
	}

	TSC_val1 = 0;
	TSC_val2 = 0;

	LCD_WriteDigit("*  ");
	HAL_Delay(1000);
	LCD_WriteDigit(" * ");
	HAL_Delay(1000);
	LCD_WriteDigit("  *");
	HAL_Delay(1000);
	LCD_WriteDigit("  o");
	HAL_Delay(1000);
	LCD_WriteDigit(" o ");
	HAL_Delay(1000);

	TSC_val1 = read_capa_value(htsc);
	if (TSC_val1 == 0) return 0;

	TSC_val2 = read_capa_value(htsc);
	if (TSC_val2 == 0) return 0;

	if (TSC_val2 > TSC_val1 * 1.05 || TSC_val2 < TSC_val1 * 0.95) return 0;

	*min_val = TSC_val1 * 0.95;

	LCD_WriteDigit("o  ");
	HAL_Delay(1000);

	LCD_WriteDigit("ok ");
	HAL_Delay(1000);

	return 1;
}
/* USER CODE END 0 */

/**
  * @brief  The application entry point.
  * @retval int
  */
int main(void)
{

  /* MCU Configuration--------------------------------------------------------*/

  /* Reset of all peripherals, Initializes the Flash interface and the Systick. */
  HAL_Init();

  /* Configure the system clock */
  SystemClock_Config();

  /* Initialize all configured peripherals */
  MX_GPIO_Init();
  MX_LCD_Init();
  MX_TSC_Init();
  MX_RTC_Init();
  /* USER CODE BEGIN 2 */
  HAL_LCD_Clear(&hlcd);

  system_flag.need_measurement = 1;

  /* USER CODE END 2 */

  /* Infinite loop */
  /* USER CODE BEGIN WHILE */
  while (1)
  {

	  switch (system_state)
	  {
	  case START:
		  if(system_flag.need_calibration)
		  {
			  system_state = CALIBRATION;
		  }
		  else if(system_flag.need_measurement)
		  {
			  system_state = MEASUREMENT;
		  }
		  else if(system_flag.low_humidity)
		  {
			  start_timer = HAL_GetTick();
			  system_state = BLINK_LED;
		  }
		  else
		  {
			  system_state = SLEEP_MODE;
		  }
		  break;

	  case CALIBRATION:
		  if(cal_capa_sensor(&HTSC_value_max, &HTSC_value_min, &htsc))
		  {
			  system_flag.need_calibration = 0;
			  system_flag.need_measurement = 1;
		  }
		  else
		  {
			  system_flag.need_calibration = 1;
		  }

		  if(system_flag.need_calibration)
		  {
			  system_state = CALIBRATION;
		  }
		  else if(system_flag.need_measurement)
		  {
			  system_state = MEASUREMENT;
		  }
		  else if(system_flag.low_humidity)
		  {
			  start_timer = HAL_GetTick();
			  system_state = BLINK_LED;
		  }
		  else
		  {
			  system_state = SLEEP_MODE;
		  }

		  break;

	  case MEASUREMENT:
		  humidity = update_capa_sensor(HTSC_value_max, HTSC_value_min, &htsc);

		  if(humidity == 200)
		  {
			  system_flag.need_measurement = 1;
		  }
		  else if(humidity < 20)
		  {
			  system_flag.need_measurement = 0;
			  system_flag.low_humidity = 1;
		  }
		  else
		  {
			  system_flag.need_measurement = 0;
		  }

		  if(system_flag.need_calibration)
		  {
			  system_state = CALIBRATION;
		  }
		  else if(system_flag.need_measurement)
		  {
			  system_state = MEASUREMENT;
		  }
		  else if(system_flag.low_humidity)
		  {
			  start_timer = HAL_GetTick();
			  system_state = BLINK_LED;
		  }
		  else
		  {
			  system_state = SLEEP_MODE;
		  }

		  break;

	  case BLINK_LED:
		  HAL_GPIO_WritePin(RED_LED_GPIO_Port, RED_LED_Pin, SET);
		  now_timer = HAL_GetTick();

		  if(now_timer - start_timer > 3000) system_flag.low_humidity = 0;

		  if(system_flag.need_calibration)
		  {
			  HAL_GPIO_WritePin(RED_LED_GPIO_Port, RED_LED_Pin, RESET);
			  system_state = CALIBRATION;
		  }
		  else if(system_flag.need_measurement)
		  {
			  HAL_GPIO_WritePin(RED_LED_GPIO_Port, RED_LED_Pin, RESET);
			  system_state = MEASUREMENT;
		  }
		  else if(system_flag.low_humidity)
		  {
			  system_state = BLINK_LED;
		  }
		  else
		  {
			  HAL_GPIO_WritePin(RED_LED_GPIO_Port, RED_LED_Pin, RESET);
			  system_state = SLEEP_MODE;
		  }

		  break;

	  case SLEEP_MODE:

		  HAL_RTCEx_SetWakeUpTimer_IT(&hrtc, 1200-1, RTC_WAKEUPCLOCK_CK_SPRE_16BITS, 0);
		  StopMode_Activated = 1;
		  HAL_SuspendTick();
		  HAL_PWREx_EnterSTOP2Mode(PWR_SLEEPENTRY_WFI);

		  HAL_RTCEx_DeactivateWakeUpTimer(&hrtc);

		  system_flag.need_measurement = 1;

		  if(system_flag.need_calibration)
		  {
			  system_state = CALIBRATION;
		  }
		  else if(system_flag.need_measurement)
		  {
			  system_state = MEASUREMENT;
		  }
		  else if(system_flag.low_humidity)
		  {
			  start_timer = HAL_GetTick();
			  system_state = BLINK_LED;
		  }
		  else
		  {
			  system_state = SLEEP_MODE;
		  }

		  break;

	  default:
		  system_state = START;
		  break;
	  }

    /* USER CODE END WHILE */

    /* USER CODE BEGIN 3 */
  }
  /* USER CODE END 3 */
}

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
/* USER CODE BEGIN 4 */
/**
  * @brief  EXTI line detection callback.
  * @param  GPIO_Pin Specifies the port pin connected to corresponding EXTI line.
  * @retval None
  */
void HAL_GPIO_EXTI_Falling_Callback(uint16_t GPIO_Pin)
{

  if(StopMode_Activated == 1)
  {
	  SystemClock_Config();
      HAL_ResumeTick();
      StopMode_Activated = 0;
  }

  if(GPIO_Pin == CAL_SW_Pin)
  {
	  system_flag.need_calibration = 1;
  }
  else if(GPIO_Pin == MES_SW_Pin)
  {
	  system_flag.need_measurement = 1;
  }
  else
  {
	  __NOP();
  }
}

void HAL_RTCEx_WakeUpTimerEventCallback(RTC_HandleTypeDef *hrtc)
{
	SystemClock_Config ();
	HAL_ResumeTick();

	StopMode_Activated = 0;

}

/* USER CODE END 4 */
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


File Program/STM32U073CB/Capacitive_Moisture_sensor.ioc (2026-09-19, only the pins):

Mcu.UserName=STM32U073CBTx
PA1.Signal=LCD_SEG0
PA10.Signal=LCD_COM2
PA2.Signal=LCD_SEG1
PA3.Signal=LCD_SEG2
PA6.Signal=LCD_SEG3
PA7.Signal=LCD_SEG4
PA8.Signal=LCD_COM0
PA9.Signal=LCD_COM1
PB0.Signal=LCD_SEG5
PB12.GPIO_Label=Probe_Capa
PB12.Signal=TSC_G1_IO1
PB13.GPIO_Label=Sampling_Capa
PB13.Signal=TSC_G1_IO2
PB2.Signal=LCD_VLCD
PB3.GPIO_Label=RED_LED
PB3.Signal=GPIO_Output
PB4.GPIO_Label=CAL_SW
PB4.Signal=GPXTI4
PB5.GPIO_Label=MES_SW
PB5.Signal=GPXTI5
PB9.Signal=LCD_COM3

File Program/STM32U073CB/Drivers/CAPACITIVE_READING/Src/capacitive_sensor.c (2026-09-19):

/*
 * capacitive_sensor.c
 *
 *  Created on: 31 juil. 2026
 *      Author: valentin
 */

#include "capacitive_sensor.h"

uint32_t read_capa_value(TSC_HandleTypeDef *htsc)
{
	uint32_t read_value = 0;

	HAL_TSC_IODischarge(htsc, ENABLE);
	HAL_Delay(1);

	// Démarrage de la mesure
	if (HAL_TSC_Start(htsc) != HAL_OK)
	{
		return 0;
	}

	// Attente de la fin de mesure (avec timeout de 10ms pour éviter de bloquer)
	if (HAL_TSC_PollForAcquisition(htsc) != HAL_OK)
	{
		return 0;
	}

	// Vérification et lecture du résultat
	if (HAL_TSC_GroupGetStatus(htsc, TSC_GROUP1_IDX) == TSC_GROUP_COMPLETED)
	{
		read_value = HAL_TSC_GroupGetValue(htsc, TSC_GROUP1_IDX);
	}

	return read_value;
}

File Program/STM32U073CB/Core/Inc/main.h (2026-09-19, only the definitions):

#define Probe_Capa_Pin GPIO_PIN_12
#define Probe_Capa_GPIO_Port GPIOB
#define Sampling_Capa_Pin GPIO_PIN_13
#define Sampling_Capa_GPIO_Port GPIOB
#define RED_LED_Pin GPIO_PIN_3
#define RED_LED_GPIO_Port GPIOB
#define CAL_SW_Pin GPIO_PIN_4
#define CAL_SW_GPIO_Port GPIOB
#define CAL_SW_EXTI_IRQn EXTI4_15_IRQn
#define MES_SW_Pin GPIO_PIN_5
#define MES_SW_GPIO_Port GPIOB
#define MES_SW_EXTI_IRQn EXTI4_15_IRQn

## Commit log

2026-07-14 Add files via upload
    adding electronics. not received yet
    [Solar_power_input.kicad_sch, Stm32_IC.kicad_sch, moisture_sensor.kicad_pcb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]
2026-09-19 ajout version 2
    [Solar_power_input.kicad_sch, Stm32_IC.kicad_sch, moisture_sensor.kicad_pcb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]
2026-09-19 add program and 3Dmodel
    [moisture_sensor_capot.3mf, moisture_sensor_capot_ecran.stl, moisture_sensor_capot_pile.stl]

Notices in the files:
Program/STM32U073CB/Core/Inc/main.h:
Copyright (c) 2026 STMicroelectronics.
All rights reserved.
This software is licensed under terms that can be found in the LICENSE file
